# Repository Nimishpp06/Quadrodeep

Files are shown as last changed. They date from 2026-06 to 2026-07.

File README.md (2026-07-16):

# QuadroDeep — Smart Attendance System

> **K. J. Somaiya Institute of Technology** — Academic IoT Project

A full-stack IoT attendance management system for academic lab environments. Combines **ESP32-based hardware** (RFID + Fingerprint) with a **Node.js backend** and **role-based web dashboards** for students, professors, and administrators.

---

## Table of Contents

- [Architecture](#architecture)
- [Features](#features)
- [Tech Stack](#tech-stack)
- [Hardware Pinout](#hardware-pinout)
- [Project Structure](#project-structure)
- [Getting Started](#getting-started)
- [Configuration](#configuration)
- [API Endpoints](#api-endpoints)
- [Team](#team)

---

## Architecture

```
┌─────────────────────────────────────────────────────────┐
│                    Frontend (Browser)                    │
│  Student Dashboard · Professor Dashboard · Admin View    │
└──────────────────────┬──────────────────────────────────┘
                       │ HTTP REST
┌──────────────────────▼──────────────────────────────────┐
│              Node.js Backend (Express)                   │
│  Authentication · Analytics · Session Management · MQTT  │
└──────┬───────────────────────────────┬──────────────────┘
       │ MQTT Pub/Sub                  │ REST
┌──────▼──────┐                 ┌──────▼──────────────────┐
│  ESP32 Node │  ◄──────────── │     Supabase (PostgreSQL) │
│  (RFID+FP)  │  light sleep   │  Attendance · Users · Labs │
└─────────────┘   wake-on-IR   └─────────────────────────┘
```

---

## Features

### Student View
- **Attendance gauge** with color-coded eligibility (≥75% green, <75% red)
- **"Can miss" counter** — how many more classes before falling below threshold
- **Punctuality tracking** — on-time vs late arrival breakdown
- **Verification mode chart** — RFID vs Fingerprint preference
- **Check-in history** — last 20 entries with status badges

### Professor View
- **Live session turnout** — present / total per session
- **Attendance trends** — 30-day line chart
- **Mode adoption pie** — RFID vs Fingerprint usage
- **At-risk flagging** — students with >15% attendance drop over 2 weeks
- **Arrival heatmap** — time-of-day distribution

### Admin View
- **Device fleet monitor** — online / offline / sleep per lab
- **Hardware alerts** — low memory, sensor errors, MQTT drops
- **Enrollment matrix** — students onboarded vs RFID vs biometric
- **Bypass audit log** — force-initialized sessions outside timetable
- **Global attendance rate** with most-utilized lab

### Hardware Capabilities
- Dual-factor authentication (RFID + Fingerprint)
- Light sleep after 5 min idle — wakes on IR motion or button press
- UART state preserved across sleep (no fingerprint re-init)
- Common-anode RGB status indicator
- Standalone offline queue with JSON storage on SPIFFS

---

## Tech Stack

| Layer | Technology |
|---|---|
| **Firmware** | Arduino / C++ (ESP32) |
| **Backend** | Node.js + Express |
| **Database** | Supabase (PostgreSQL) |
| **Frontend** | Vanilla JS + Chart.js |
| **Messaging** | MQTT (Mosquitto) |
| **Biometrics** | R307 / AS608 Fingerprint Scanner |
| **RFID** | MFRC522 |
| **Display** | I2C LCD 16×2 |
| **Power** | Light sleep (ESP32 deep sleep variant) |

---

## Hardware Pinout

| Component | ESP32 Pin | Bus |
|---|---|-----|
| RFID RST | GPIO 4 | — |
| RFID MISO | GPIO 19 | SPI |
| RFID MOSI | GPIO 23 | SPI |
| RFID SCK | GPIO 18 | SPI |
| RFID SDA/SS | GPIO 5 | SPI |
| Fingerprint RX (ESP TX2) | GPIO 17 | UART2 |
| Fingerprint TX (ESP RX2) | GPIO 16 | UART2 |
| Buzzer | GPIO 14 | — |
| IR / PIR Motion | GPIO 33 | — (wake source) |
| Push Button | GPIO 32 | — (wake source) |
| I2C SDA | GPIO 21 | I2C |
| I2C SCL | GPIO 22 | I2C |
| RGB Red | GPIO 27 | Common anode |
| RGB Green | GPIO 26 | Common anode |
| RGB Blue | GPIO 25 | Common anode |

---

## Project Structure

```
QuadroDeep/
├── QuadroDeep_Node/          # ESP32 firmware
│   ├── QuadroDeep_Node.ino   # Main state machine
│   ├── config.h              # Pins, WiFi, MQTT, API base
│   ├── hardware.h            # Init / wake / sleep helpers
│   ├── wifi_manager.h        # WiFi provisioning
│   ├── storage.h             # SPIFFS offline queue
│   └── device_base64.h       # Base64 fingerprint templates
├── backend/                  # Node.js server
│   ├── server.js             # Express app + routes
│   ├── jobs/                 # Cron jobs (reminders)
│   ├── services/             # Notification service
│   ├── templates/            # Email templates
│   ├── utils/                # Helpers (Resend, retry)
│   ├── package.json
│   └── .env.example          # Required environment variables
├── index.html                # Web dashboard
├── QuadroDeep-Logo.png
└── somaiya-logo.png
```

---

## Getting Started

### Prerequisites

- Node.js v18+
- Supabase (PostgreSQL) project
- Mosquitto MQTT broker
- ESP32 with Arduino IDE
- R307 / AS608 fingerprint sensor + MFRC522 RFID module

### Backend

```bash
cd backend
cp .env.example .env    # Edit with your credentials
npm install
node server.js
```

### ESP32 Firmware

1. Open `QuadroDeep_Node/QuadroDeep_Node.ino` in Arduino IDE
2. Install libraries: `MFRC522`, `Adafruit_Fingerprint`, `LiquidCrystal_I2C`, `PubSubClient`, `ArduinoJson`
3. Edit `config.h`:
   - Set `WIFI_SSID` / `WIFI_PASSWORD`
   - Set `API_BASE` to your backend IP
   - Set `MQTT_BROKER` to your broker IP
4. Upload to ESP32

### Frontend

Serve `index.html` via Live Server (port 5501) or any static server.

---

## Configuration

### Backend (`backend/.env`)

| Variable | Description |
|---|---|
| `PORT` | Server port (default: 3000) |
| `SUPABASE_URL` | Supabase project URL |
| `SUPABASE_SERVICE_KEY` | Supabase service-role JWT |
| `MQTT_BROKER_URL` | `mqtt://<broker-ip>:1885` |
| `RESEND_API_KEY` | Resend email API key |
| `FROM_EMAIL` | Sender email address |

### ESP32 (`QuadroDeep_Node/config.h`)

| Constant | Description |
|---|---|
| `API_BASE` | Backend URL (e.g. `http://192.168.1.100:3000`) |
| `LAB_ID` | Lab identifier (e.g. `IOT_01`) |
| `WIFI_SSID` | WiFi network name |
| `WIFI_PASSWORD` | WiFi password |
| `MQTT_BROKER` | Broker IP address |

---

## API Endpoints

| Method | Endpoint | Role | Purpose |
|---|---|---|---|
| `GET` | `/api/analytics/student/:id` | Student | Attendance %, eligibility, punctuality, mode pie, history |
| `GET` | `/api/analytics/professor/dashboard` | Professor | Session stats, 30-day trends, at-risk list, mode split |
| `GET` | `/api/analytics/professor/heatmap` | Professor | Arrival time bucket distribution |
| `GET` | `/api/analytics/admin/overview` | Admin | Users, labs, devices, attendance rate, alerts |
| `GET` | `/api/analytics/admin/enrollment-progress` | Admin | RFID vs biometric onboarding |
| `GET` | `/api/analytics/admin/bypass-log` | Admin | Force-init session audit trail |

---

## Adafruit Fingerprint Library Patch

This project uses a patched version of `Adafruit_Fingerprint` that adds **UPCHAR / DOWNCHAR** support for raw template upload and download — enabling fingerprint backup, restore, and sensor cloning.

The patched library files are in [`adafruit-patch/`](./adafruit-patch/), and also maintained as a standalone repository:
**[github.com/Nimishpp06/adafruit-fingerprint-updown](https://github.com/Nimishpp06/adafruit-fingerprint-updown)**

---

## Team

- **Nimish Patil**
- **Ashley Dsilva**
- **Sweekar Mandavkar**
- **Dhruv Maurya**

**K. J. Somaiya school of engineering, Vidyavihar Mumbai**

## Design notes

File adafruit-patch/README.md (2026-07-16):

# Adafruit Fingerprint Library — R307 Template Upload/Download Patch

Adds `readCharBuffer()` and `writeCharBuffer()` support to the official `Adafruit_Fingerprint` library, enabling **fingerprint template cloning** on R307 / AS608 sensors.

## What's Added

| Function | Command | Purpose |
|---|---|---|
| `readCharBuffer(bufferID, outBuf, &outLen)` | UPCHAR `0x08` | Upload a raw 512-byte template from sensor buffer to MCU |
| `writeCharBuffer(bufferID, data, len)` | DOWNCHAR `0x09` | Download a raw template from MCU back to sensor buffer |
| `match(&score)` | `0x03` | Compare two buffers already in slots 1 and 2 |

## Why It's Needed

The official library has no support for reading raw templates from or writing them to the sensor. Without these functions, you cannot:
- Backup enrolled fingerprints
- Clone a sensor configuration to another unit
- Store templates in external flash and restore later

## Key Implementation Details

- **DOWNCHAR** (`writeCharBuffer`): streams data in 128-byte chunks with `DATAPACKET`/`ENDDATAPACKET` framing. The R307 **does not send an ACK** after the final data packet — waiting for one causes a timeout. This patch correctly skips the final ACK read.
- **UPCHAR** (`readCharBuffer`): response can exceed the original 256-byte internal buffer; bumped to **1024 bytes**.
- A **15 ms delay** between DOWNCHAR chunks is required for the sensor to process each packet.

## Files

- `Adafruit_Fingerprint.h` — patched header with new method declarations and `#define FINGERPRINT_UPCHAR 0x08`
- `Adafruit_Fingerprint.cpp` — patched implementation of `readCharBuffer`, `writeCharBuffer`, `match`
- `R307_Clone_Test.ino` — test sketch: enroll → upload → erase → download → store → verify

## Usage

Copy `Adafruit_Fingerprint.h` and `Adafruit_Fingerprint.cpp` into your Arduino `libraries/Adafruit_Fingerprint/` directory, replacing the originals. Then upload `R307_Clone_Test.ino` to your ESP32.

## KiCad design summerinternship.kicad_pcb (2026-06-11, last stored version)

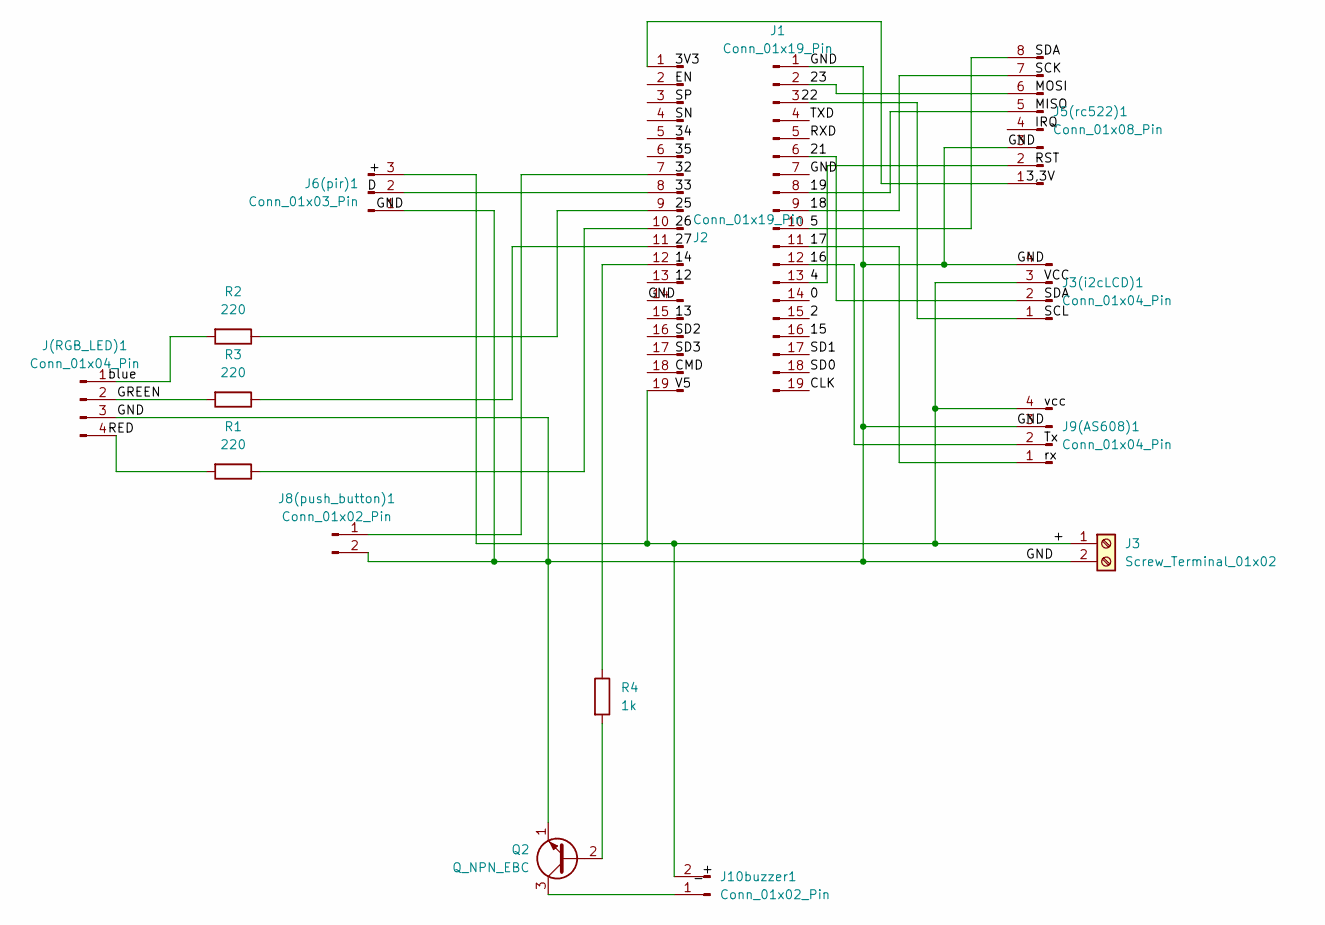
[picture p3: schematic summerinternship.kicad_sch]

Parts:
J1, J2: Conn_01x19_Pin; PinHeader_1x19_P2.54mm_Vertical
J3: Screw_Terminal_01x02; TerminalBlock_MaiXu_MX126-5.0-02P_1x02_P5.00mm
J3(i2cLCD)1, J9(AS608)1: Conn_01x04_Pin; PinHeader_1x04_P2.54mm_Vertical
J5(rc522)1: Conn_01x08_Pin; PinSocket_1x08_P2.54mm_Vertical
J6(pir)1: Conn_01x03_Pin; PinHeader_1x03_P2.54mm_Vertical
J8(push_button)1, J10buzzer1: Conn_01x02_Pin; PinHeader_1x02_P2.54mm_Vertical
J(RGB_LED)1: Conn_01x04_Pin; PinHeader_1x04_P2.54mm_Vertical
Q2: Q_NPN_EBC; PinHeader_1x03_P2.54mm_Vertical
R1, R2, R3: 220; R_Axial_DIN0207_L6.3mm_D2.5mm_P7.62mm_Horizontal
R4: 1k; R_Axial_DIN0207_L6.3mm_D2.5mm_P7.62mm_Horizontal

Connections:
/0: J1.14
/2: J1.15
/4: J1.13, J5(rc522)1.2
/5: J1.10, J5(rc522)1.8
/15: J1.16
/16: J1.12, J9(AS608)1.2
/17: J1.11, J9(AS608)1.1
/18: J1.9, J5(rc522)1.7
/19: J1.8, J5(rc522)1.5
/21: J1.6, J3(i2cLCD)1.2
/23: J1.2, J5(rc522)1.6
/+: J2.19, J3.1, J3(i2cLCD)1.3, J6(pir)1.3, J9(AS608)1.4, J10buzzer1.2
/CLK: J1.19
/GND: J1.1, J1.7, J2.14, J3.2, J3(i2cLCD)1.4, J5(rc522)1.3, J6(pir)1.1, J8(push_button)1.2, J9(AS608)1.3, J(RGB_LED)1.3, Q2.1 (E)
/GREEN: J(RGB_LED)1.2, R3.2
/RXD: J1.5
/SD0: J1.18
/SD1: J1.17
/TXD: J1.4
unnamed: J1.3, J3(i2cLCD)1.1
unnamed: J2.1, J5(rc522)1.1
unnamed: J2.7, J8(push_button)1.1
unnamed: J2.8, J6(pir)1.2
unnamed: J2.9, R2.1
unnamed: J2.10, R1.1
unnamed: J2.11, R3.1
unnamed: J2.12, R4.1
unnamed: J10buzzer1.1, Q2.3 (C)
unnamed: J(RGB_LED)1.1, R2.2
unnamed: J(RGB_LED)1.4, R1.2
unnamed: Q2.2 (B), R4.2

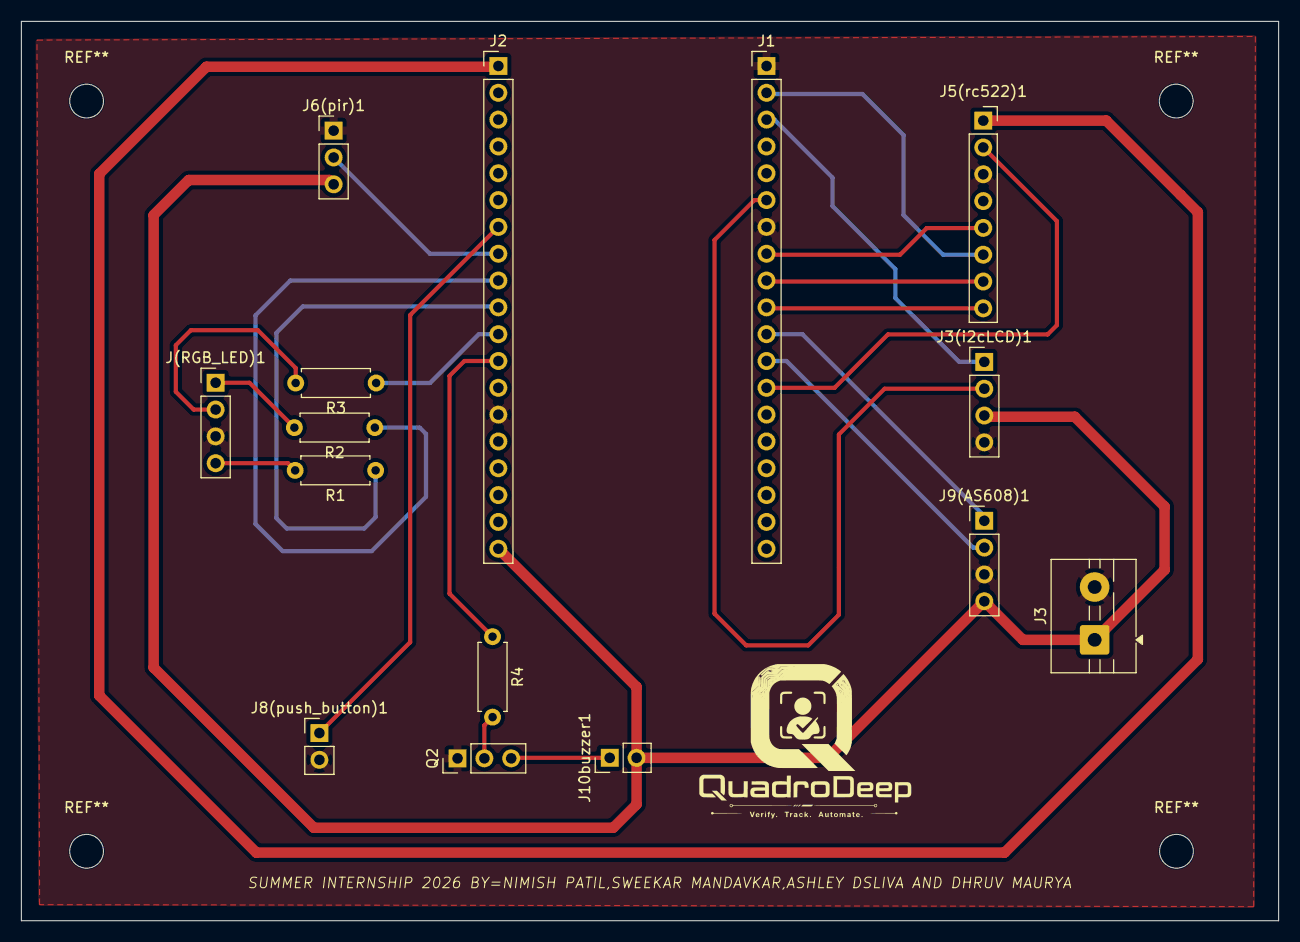
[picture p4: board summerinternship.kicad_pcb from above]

Board: 2 copper layers, 119.1 x 85.2 mm, 15 parts (0 on the bottom side), 23 nets.

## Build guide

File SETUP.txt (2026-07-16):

━━━━━━━━━━━━━━━━━━━━━━━━━━━━━━━━━━━━━━━━━━━━━━━━━━
  QUADRODEEP — SETUP INSTRUCTIONS
━━━━━━━━━━━━━━━━━━━━━━━━━━━━━━━━━━━━━━━━━━━━━━━━━━

1. BACKEND SETUP
─────────────────
   cd backend
   cp .env.example .env
   # Edit .env with your Supabase & MQTT credentials
   npm install
   node server.js

2. DATABASE
─────────────────
   Create a Supabase project and run the schema
   defined in backend/templates/ (tables, indexes, RLS)

3. MQTT BROKER
─────────────────
   Install Mosquitto (or any MQTT broker).
   Default expects broker at 192.168.137.1:1885.

4. ESP32 FIRMWARE
─────────────────
   Open QuadroDeep_Node/QuadroDeep_Node.ino in Arduino IDE.
   Install libraries:
     - MFRC522
     - Adafruit_Fingerprint
     - LiquidCrystal_I2C
     - PubSubClient
     - ArduinoJson
   Edit QuadroDeep_Node/config.h:
     - Set WIFI_SSID / WIFI_PASSWORD
     - Set API_BASE to your backend URL
     - Set MQTT_BROKER to your broker IP
   Upload to ESP32.

5. FRONTEND
─────────────────
   Open index.html in a browser, or serve via
   Live Server (VSCode extension) on port 5501.

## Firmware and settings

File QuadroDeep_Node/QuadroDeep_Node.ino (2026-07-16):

#include "config.h"
#include "hardware.h"
#include "wifi_manager.h"
#include "storage.h"
#include "device_base64.h"
#include <Preferences.h>
#include <LittleFS.h>
#include <driver/rtc_io.h>
#include <PubSubClient.h>

// ===== GLOBAL INSTANCES =====
DeviceNetworkManager net;

// ===== GLOBAL STATE =====
AppState currentState = STATE_BOOT;
SessionConfig activeSession;
unsigned long lastActivity = 0;
unsigned long lastHeartbeat = 0;
unsigned long lastMqttReconnect = 0;
unsigned long lastHttpPoll = 0;
bool mqttEverConnected = false;
bool mqttFailed = false;

// Track which students already marked this session to prevent duplicate scans
bool attendanceMarked[30] = {false};

// Track last processed command ID to avoid re-processing stale commands
int lastProcessedCmdId = -1;

// Guard flag to disable sleep during biometric enrollment
bool isEnrollmentActive = false;

// Timer for countdown flash intervals
unsigned long lastFlashTime = 0;

// Offline RFID mode
unsigned long lastWifiCheck = 0;
bool wifiReconnecting = false;

// ===== PROTOTYPES =====
void handleCommand(JsonDocument& cmd);
void processRFID();
void processFingerprint();
uint16_t nextAvailableSlot();
void markAttendance(String studentId, String studentName, String method, String rfidHex = "", uint16_t fingerId = 0);
bool connectMQTT();
void processOfflineRFID();
void handleActiveSessionTimeout();
void enterLightSleep(bool isTimeout);
void maintainConnections();
void updateLiveSessionDisplay();

// ===== MQTT =====
WiFiClient espClient;
PubSubClient mqttClient(espClient);

void mqttCallback(char* topic, byte* payload, unsigned int length) {
    char msg[length + 1];
    memcpy(msg, payload, length);
    msg[length] = '\0';
    Serial.printf("[MQTT] Received on %s: %s\n", topic, msg);

    JsonDocument doc;
    DeserializationError err = deserializeJson(doc, msg);
    if (err) { Serial.println("[MQTT] JSON parse error"); return; }

    String command = doc["command"].as<String>();

    if (command == "START") {
        Serial.println("[MQTT] START command received");
        activeSession.sessionId = doc["session_id"].as<String>();
        activeSession.mode = doc["mode"].as<String>();
        activeSession.startTime = doc["start_time"].as<time_t>();
        activeSession.endTime = doc["end_time"].as<time_t>();
        lastActivity = millis();
        currentState = STATE_CHECK_ACTIVE_SESSION;
    }
    else if (command == "END") {
        Serial.println("[MQTT] END command received");
        activeSession = SessionConfig();
        currentState = STATE_IDLE;
    }
    else if (command == "SET_MODE") {
        Serial.println("[MQTT] SET_MODE command received");
        activeSession.mode = doc["mode"].as<String>();
    }
    else if (command == "ENROLL_RFID") {
        Serial.println("[MQTT] RFID enrollment command received");
        JsonDocument fakeCmd;
        fakeCmd["data"]["type"] = "rfid";
        fakeCmd["data"]["id"] = doc["cmd_id"].as<int>();
        fakeCmd["data"]["target_user_id"] = doc["target_user_id"].as<String>();
        handleCommand(fakeCmd);
    }
    else if (command == "ENROLL_FINGERPRINT") {
        Serial.println("[MQTT] FP enrollment command received");
        JsonDocument fakeCmd;
        fakeCmd["data"]["type"] = "fingerprint";
        fakeCmd["data"]["id"] = doc["cmd_id"].as<int>();
        fakeCmd["data"]["target_user_id"] = doc["target_user_id"].as<String>();
        handleCommand(fakeCmd);
    }
}

// ===== PREFERENCES HELPERS =====
uint16_t getNextFingerSlot() {
    Preferences prefs;
    prefs.begin("finger", false);
    uint16_t slot = prefs.getUShort(PREFS_FINGER_SLOT, 1);
    prefs.end();
    if (slot > 200) slot = 1;
    return slot;
}

void saveNextFingerSlot(uint16_t slot) {
    Preferences prefs;
    prefs.begin("finger", false);
    prefs.putUShort(PREFS_FINGER_SLOT, slot);
    prefs.end();
}

uint16_t nextAvailableSlot() {
    uint16_t slot = getNextFingerSlot();
    saveNextFingerSlot(slot + 1);
    if (slot > 200) { saveNextFingerSlot(1); return 1; }
    return slot;
}

// ===== SETUP =====
void setup() {
    Serial.begin(115200);
    delay(500); // Give the serial monitor a moment to catch up
    
    // DIAGNOSTIC PRINT: To prove the new code actually uploaded successfully
    Serial.println("\n\n====================================");
    Serial.println("!!! ESP32 BOOTED - NEW CODE ACTIVE !!!");
    Serial.println("====================================");
    
    lastActivity = millis();
}
// ===== MAIN LOOP =====
void loop() {
    switch (currentState) {
        case STATE_BOOT:
            currentState = STATE_INIT_HARDWARE;
            break;

        case STATE_INIT_HARDWARE:
            hw.init();
            store.init();
            hw.display("QuadroDeep", "Connecting...");
            currentState = STATE_WIFI_PROVISION;
            break;

        case STATE_WIFI_PROVISION:
            hw.setRGB(0, 0, 255); 
            net.connectWiFi();    
            currentState = STATE_SYNC_TIME;
            break;

        case STATE_SYNC_TIME:
            net.syncTime();
            currentState = STATE_REGISTER_DEVICE;
            break;

        case STATE_REGISTER_DEVICE: {
            bool registered = false;
            for (int retry = 0; retry < 3 && !registered; retry++) {
                JsonDocument req;
                req["labId"] = LAB_ID;
                req["firmwareVersion"] = FIRMWARE_VERSION;
                String payload; serializeJson(req, payload);
                
                String res = net.httpPost("/api/device/register", payload);
                if (res.length() > 0) {
                    registered = true;
                } else {
                    Serial.printf("[REGISTER] Attempt %d failed, retrying...\n", retry + 1);
                    delay(2000);
                }
            }
            
            currentState = STATE_MQTT_CONNECT;
            break;
        }

        case STATE_CHECK_ACTIVE_SESSION: {
            hw.display("Loading Students...", activeSession.sessionId);
            Serial.printf("[STATE] CHECK_ACTIVE_SESSION: loading biometrics for sessionId=%s\n", activeSession.sessionId.c_str());
            String res = net.httpGet("/api/professor/session/biometrics?sessionId=" + activeSession.sessionId);
            JsonDocument doc; deserializeJson(doc, res);
            Serial.printf("[STATE] CHECK_ACTIVE_SESSION: HTTP response (first 200 chars): %s\n", res.substring(0, 200).c_str());
            
            if (doc["success"]) {
                JsonArray students = doc["data"]["students"].as<JsonArray>();
                activeSession.studentCount = 0;
                memset(attendanceMarked, 0, sizeof(attendanceMarked));
                
                activeSession.mode = doc["data"]["mode"].as<String>();
                
                for (JsonObject s : students) {
                    if (activeSession.studentCount < 30) {
                        StudentRecord& rec = activeSession.students[activeSession.studentCount];
                        rec.id = s["id"].as<String>();
                        rec.name = s["name"].as<String>();
                        rec.rfid = s["rfid"].as<String>();
                        rec.sessionFingerId = s["fingerId"].as<uint16_t>();
                        rec.rs307Slot = s["fingerId"].as<uint16_t>(); 
                        rec.hasRfid = (s["rfid"].as<String>().length() > 0);
                        rec.hasFingerprint = (s["biometric"].as<String>().length() > 0);
                        Serial.printf("[STATE] student[%d]: name=%s, rfid=%s, rs307Slot=%d\n",
                            activeSession.studentCount, rec.name.c_str(), rec.rfid.c_str(), rec.rs307Slot);
                        activeSession.studentCount++;
                    }
                }
                Serial.printf("[STATE] Session loaded: %d students, mode=%s\n", activeSession.studentCount, activeSession.mode.c_str());
                currentState = STATE_SESSION_ACTIVE;
            } else {
                currentState = STATE_IDLE;
            }
            break;
        }

        case STATE_MQTT_CONNECT:
            hw.display("Connecting MQTT", "");
            hw.setRGB(0, 0, 255);
            if (connectMQTT()) {
                currentState = STATE_IDLE;
            } else {
                currentState = STATE_IDLE;
            }
            break;

        case STATE_IDLE:
            hw.setRGB(0, 255, 0); 
            hw.display("No Session Live", "Ready to Trigger");

            if (mqttClient.connected()) {
                mqttClient.loop();
            } else if (!mqttFailed && !mqttEverConnected) {
                unsigned long now = millis();
                if (now - lastMqttReconnect > 30000) {
                    lastMqttReconnect = now;
                    connectMQTT();
                }
            } else if (mqttEverConnected && !mqttClient.connected()) {
                unsigned long now = millis();
                if (now - lastMqttReconnect > 30000) {
                    lastMqttReconnect = now;
                    connectMQTT();
                }
            }

            if (millis() - lastHttpPoll > 5000) {
                lastHttpPoll = millis();
                String res = net.httpGet("/api/device/command?labId=" + String(LAB_ID));
                if (res.length() > 0) {
                    JsonDocument cmd; deserializeJson(cmd, res);
                    if (cmd["success"] && !cmd["data"].isNull()) {
                        int cmdId = cmd["data"]["id"].as<int>();
                        if (cmdId != lastProcessedCmdId) {
                            lastProcessedCmdId = cmdId;
                            String type = cmd["data"]["type"].as<String>();
                            if (type == "load_session") {
                                activeSession.sessionId = cmd["data"]["target_user_id"].as<String>();
                                activeSession.mode = cmd["data"]["result_value"].as<String>();
                                currentState = STATE_CHECK_ACTIVE_SESSION;
                            } else if (type == "end_session") {
                                activeSession = SessionConfig();
                                currentState = STATE_IDLE;
                            } else if (type == "rfid" || type == "fingerprint" || type == "start_enrollment" || type == "end_enrollment" || type == "set_mode") {
                                handleCommand(cmd);
                            }
                        }
                    }
                }
            }

            // WiFi lost → offline RFID mode
            if (!net.isConnected() && millis() - lastWifiCheck > 10000) {
                lastWifiCheck = millis();
                Serial.println("[WIFI] Lost connection → entering OFFLINE mode");
                hw.display("Lost WiFi", "Going Offline");
                delay(1000);
                currentState = STATE_OFFLINE;
            }

            // 5-minute idle timeout → light sleep
            if (!isEnrollmentActive && millis() - lastActivity > 300000) {
                Serial.println("[IDLE] 5-minute timeout reached. Suspending...");
                enterLightSleep(false);
            }
            break;

        case STATE_OFFLINE: {
            hw.setRGB(255, 165, 0);
            hw.display("OFFLINE MODE", "Tap RFID Card");

            // Non-blocking WiFi reconnect: start once, check progress each loop
            if (!wifiReconnecting && !net.isConnected()) {
                Serial.println("[OFFLINE] Starting WiFi reconnect attempt...");
                WiFi.begin(WIFI_SSID, WIFI_PASSWORD);
                wifiReconnecting = true;
                lastWifiCheck = millis();
            }

            // Every 5s, check if WiFi connected yet
            if (wifiReconnecting && millis() - lastWifiCheck > 5000) {
                lastWifiCheck = millis();
                if (WiFi.status() == WL_CONNECTED) {
                    wifiReconnecting = false;
                    Serial.printf("[OFFLINE] WiFi reconnected! IP: %s\n", WiFi.localIP().toString().c_str());

                    // Let TCP/IP stack settle before HTTP
                    delay(1000);

                    hw.setRGB(255, 255, 0);
                    hw.display("WiFi Back!", "Syncing...");
                    delay(500);

                    String queue = store.getOfflineRFIDQueue();
                    Serial.printf("[SYNC] Queue length: %d chars, content: %s\n", queue.length(), queue.substring(0, 100).c_str());

                    if (queue.length() > 5) {
                        JsonDocument req;
                        req["labId"] = LAB_ID;
                        req["records"] = serialized(queue);
                        String payload; serializeJson(req, payload);

                        hw.display("Syncing...", String(payload.length()) + " bytes");
                        Serial.printf("[SYNC] POSTing to /api/attendance/offline-rfid-sync, payload: %s\n", payload.c_str());

                        String res = net.httpPost("/api/attendance/offline-rfid-sync", payload);
                        Serial.printf("[SYNC] HTTP response (%d chars): %s\n", res.length(), res.c_str());

                        if (res.length() > 0) {
                            JsonDocument resp; deserializeJson(resp, res);
                            if (resp["success"]) {
                                store.clearOfflineRFIDQueue();
                                int p = resp["data"]["processed"].as<int>();
                                hw.setRGB(0, 255, 0);
                                hw.display("Sync OK", String(p) + " processed");
                                Serial.printf("[SYNC] Success! Processed %d records\n", p);
                                delay(1500);
                            } else {
                                String err = resp["error"].as<String>();
                                hw.setRGB(255, 0, 0);
                                hw.display("Sync Failed", err.length() > 0 ? err : "Server error");
                                Serial.printf("[SYNC] Server returned error: %s\n", err.c_str());
                                delay(1500);
                            }
                        } else {
                            hw.setRGB(255, 0, 0);
                            hw.display("Sync Error", "HTTP failed");
                            Serial.println("[SYNC] HTTP POST returned empty response");
                            delay(1500);
                        }
                    } else {
                        Serial.println("[SYNC] Queue empty or too short, skipping sync");
                    }
                    currentState = STATE_IDLE;
                    break;
                } else {
                    Serial.printf("[OFFLINE] WiFi not connected yet, status=%d\n", WiFi.status());
                }
            }

            // Keep MQTT alive when WiFi is connected
            if (net.isConnected()) {
                if (mqttClient.connected()) {
                    mqttClient.loop();
                } else if (mqttEverConnected) {
                    if (millis() - lastMqttReconnect > 30000) {
                        lastMqttReconnect = millis();
                        connectMQTT();
                    }
                }
            }

            processOfflineRFID();
            break;
        }

        case STATE_SESSION_ACTIVE: {
            if (mqttClient.connected()) {
                mqttClient.loop();
            } else if (mqttEverConnected || !mqttFailed) {
                unsigned long ms = millis();
                if (ms - lastMqttReconnect > 30000) {
                    lastMqttReconnect = ms;
                    connectMQTT();
                }
            }

            updateLiveSessionDisplay();

            time_t now = net.getCurrentLocalTime();
            if (activeSession.endTime > 0 && now >= activeSession.endTime) {
                hw.display("Session Ended", "");
                delay(2000);
                activeSession = SessionConfig(); 
                currentState = STATE_IDLE;
                break;
            }

            if (millis() - lastHeartbeat > 30000) {
                lastHeartbeat = millis();
                if (net.isConnected()) {
                    String queue = store.getOfflineQueuePayload();
                    if (queue.length() > 20) {
                        net.httpPost("/api/attendance/sync-offline", queue);
                        store.clearOfflineQueue();
                    }
                    JsonDocument hb;
                    hb["labId"] = LAB_ID;
                    hb["freeHeap"] = ESP.getFreeHeap();
                    hb["uptime"] = millis() / 1000;
                    String hStr; serializeJson(hb, hStr);
                    net.httpPost("/api/device/heartbeat", hStr);
                }
            }

            processRFID();
            processFingerprint();

            // Evaluate sleep requirements ONLY if enrollment mode is inactive
            if (!isEnrollmentActive) {
                handleActiveSessionTimeout();
            }
        }
    }
}

// ===== MQTT CONNECTION =====
bool connectMQTT() {
    mqttClient.setServer(MQTT_BROKER, MQTT_PORT);
    mqttClient.setCallback(mqttCallback);

    String clientId = "ESP32_" + String(LAB_ID) + "_" + String(random(0xffff), HEX);

    for (int retry = 0; retry < 3; retry++) {
        if (mqttClient.connect(clientId.c_str())) {
            Serial.println("[MQTT] Connected!");
            mqttClient.subscribe(MQTT_TOPIC_CONTROL);
            Serial.printf("[MQTT] Subscribed to %s\n", MQTT_TOPIC_CONTROL);
            mqttEverConnected = true;
            mqttFailed = false;
            return true;
        }
        delay(300);
    }
    if (!mqttEverConnected) mqttFailed = true;
    return false;
}
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

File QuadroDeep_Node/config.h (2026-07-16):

#ifndef CONFIG_H
#define CONFIG_H

#include <Arduino.h>
#define API_BASE "http://192.168.137.1:3000"
#define LAB_ID "IOT_01"
#define FIRMWARE_VERSION "1.0.0"

#define WIFI_SSID "NIMISH 3333"
#define WIFI_PASSWORD "71@J838j"

// MQTT Configuration
#define MQTT_BROKER "192.168.137.1"
#define MQTT_PORT 1885
#define MQTT_TOPIC_CONTROL "lab/" LAB_ID "/control"
#define MQTT_TOPIC_STATUS "lab/" LAB_ID "/status"

// Hardware Pins
#define PIN_RFID_RST 4
#define PIN_RFID_MISO 19
#define PIN_RFID_MOSI 23
#define PIN_RFID_SCK 18
#define PIN_RFID_SS 5

#define PIN_FP_RX 16 // ESP32 RX2 -> RS307 TX
#define PIN_FP_TX 17 // ESP32 TX2 -> RS307 RX

#define PIN_BUZZER 14
#define PIN_PIR 33
#define PIN_BUTTON 32

#define PIN_I2C_SDA 21
#define PIN_I2C_SCL 22

#define PIN_RGB_R 27
#define PIN_RGB_G 26
#define PIN_RGB_B 25

// Constants
#define OFFLINE_QUEUE_FILE "/offline_queue.json"
#define OFFLINE_RFID_FILE "/offline_rfid.json"
#define PREFS_FINGER_SLOT "next_finger_slot"

// Global Enums
enum AppState {
    STATE_BOOT,
    STATE_INIT_HARDWARE,
    STATE_WIFI_PROVISION,
    STATE_SYNC_TIME,
    STATE_REGISTER_DEVICE,
    STATE_CHECK_ACTIVE_SESSION,
    STATE_MQTT_CONNECT,
    STATE_IDLE,
    STATE_SESSION_ACTIVE,
    STATE_OFFLINE
};

// Data Structures
struct StudentRecord {
    String id;
    String name;
    String rfid;
    uint16_t rs307Slot;       // 1-200 (Internal hardware memory slot)
    uint16_t sessionFingerId; // 1-30 (Backend session ID)
    bool hasRfid;
    bool hasFingerprint;
};

struct SessionConfig {
    String sessionId;
    String labId;
    String batchId;
    String mode;
    time_t startTime = 0;      // Session start (epoch)
    time_t endTime = 0;        // Session end (epoch)
    StudentRecord students[30];
    int studentCount = 0;
};

// Function Declarations from Main
uint16_t getNextFingerSlot();
void saveNextFingerSlot(uint16_t slot);

#endif // CONFIG_H

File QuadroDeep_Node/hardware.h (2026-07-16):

#ifndef HARDWARE_H
#define HARDWARE_H

#include "config.h"
#include <Wire.h>
#include <SPI.h>
#include <LiquidCrystal_I2C.h>
#include <MFRC522.h>
#include <Adafruit_Fingerprint.h>
#include <driver/rtc_io.h> // ESP32 core 3.x RTC requirement

class HardwareManager {
public:
    LiquidCrystal_I2C lcd;
    MFRC522 rfid;
    Adafruit_Fingerprint finger;

    HardwareManager() : lcd(0x27, 16, 2), rfid(PIN_RFID_SS, PIN_RFID_RST), finger(&Serial2) {}

    void init() {
        Wire.begin(PIN_I2C_SDA, PIN_I2C_SCL);
        lcd.init();
        lcd.backlight();
        
        pinMode(PIN_RGB_R, OUTPUT);
        pinMode(PIN_RGB_G, OUTPUT);
        pinMode(PIN_RGB_B, OUTPUT);
        pinMode(PIN_BUZZER, OUTPUT);
        setRGB(0, 0, 0); 
        
        SPI.begin(PIN_RFID_SCK, PIN_RFID_MISO, PIN_RFID_MOSI, PIN_RFID_SS);
        rfid.PCD_Init();
        rfid.PCD_SetAntennaGain(rfid.RxGain_max); // using RxGain_max as it's the valid enum for MFRC522
        
        Serial2.begin(57600, SERIAL_8N1, PIN_FP_RX, PIN_FP_TX);
        finger.begin(57600);
        if (!finger.verifyPassword()) {
            Serial.println("FP sensor NOT found!");
        } else {
            Serial.println("FP sensor OK");
        }
    }

    void display(String line1, String line2) {
        lcd.clear();
        lcd.setCursor(0, 0); lcd.print(line1);
        lcd.setCursor(0, 1); lcd.print(line2);
    }

    void setRGB(uint8_t r, uint8_t g, uint8_t b) {
        // Common Anode: 0=ON, 255=OFF (inverted)
        analogWrite(PIN_RGB_R, 255 - r);
        analogWrite(PIN_RGB_G, 255 - g);
        analogWrite(PIN_RGB_B, 255 - b);
    }

    void beep(int duration, int times = 1) {
        for(int i = 0; i < times; i++) {
            digitalWrite(PIN_BUZZER, HIGH);
            delay(duration);
            digitalWrite(PIN_BUZZER, LOW);
            if(times > 1 && i < times - 1) delay(duration);
        }
    }

    void wakeInit() {
        Wire.begin(PIN_I2C_SDA, PIN_I2C_SCL);
        lcd.init();
        lcd.backlight();
        
        pinMode(PIN_RGB_R, OUTPUT);
        pinMode(PIN_RGB_G, OUTPUT);
        pinMode(PIN_RGB_B, OUTPUT);
        pinMode(PIN_BUZZER, OUTPUT);
        setRGB(0, 0, 0); 
        
        SPI.begin(PIN_RFID_SCK, PIN_RFID_MISO, PIN_RFID_MOSI, PIN_RFID_SS);
        rfid.PCD_Init();
        rfid.PCD_SetAntennaGain(rfid.RxGain_max);
        
        if (!finger.verifyPassword()) {
            Serial.println("FP sensor unresponsive after wake, re-initializing...");
            Serial2.begin(57600, SERIAL_8N1, PIN_FP_RX, PIN_FP_TX);
            finger.begin(57600);
            if (!finger.verifyPassword()) {
                Serial.println("FP sensor NOT found after wake!");
            } else {
                Serial.println("FP sensor recovered OK");
            }
        } else {
            Serial.println("FP sensor OK (no re-init needed)");
        }
    }

    void sleepPrepare() {
        lcd.noBacklight();
        lcd.clear();
        digitalWrite(PIN_RGB_R, HIGH);
        digitalWrite(PIN_RGB_G, HIGH);
        digitalWrite(PIN_RGB_B, HIGH);
        rfid.PCD_AntennaOff();
    }
};

extern HardwareManager hw;
HardwareManager hw;

#endif // HARDWARE_H

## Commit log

2026-07-16 Clean repo, professional README, add adafruit-patch
    - Remove dev artifacts: python/ scripts, zip, KiCad files
    - Rewrite README with table of contents, architecture diagram,
    configuration tables, API docs, professional formatting
    - Update .gitignore to exclude IDE, OS, and build artifacts
    - Add adafruit-patch/: modified Adafruit_Fingerprint library with
    readCharBuffer/writeCharBuffer (UPCHAR/DOWNCHAR) + test sketch
    [summerinternship.kicad_pcb, summerinternship.kicad_sch]
2026-07-16 Add reference to adafruit-fingerprint-updown repo
